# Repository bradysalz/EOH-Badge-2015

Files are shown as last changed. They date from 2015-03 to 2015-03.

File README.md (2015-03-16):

# EOH Badge 2015
This repo has the badges I designed for University of Illinois' [Engineering Open House] (http://eoh.ec.illinois.edu). The [student branch of IEEE] (http://ieee.illinois.edu) funded the creation of about 350 of these little guys, and they were a huge hit with the crowd!

badge

## How It Works
We flashed simple Arduino code onto a ATtiny85's in order to sample the voltage level between a photocell and a resistor. The sampling had a period of around 50ms, or 20Hz. If it detected a change from light to dark in that time period, it would turn on and slowly fade out the LEDs. 

## To Do
- [ ] Swap from polling to interrupt code ( ISR ADC_vect)
- [x] Add pin clasps to BOM somehow?
- [x] Edit PCB to properly handle SPDT switch (currently in parallel AKA useless)
- [x] Edit PCB to wire RESET to VDD (had to write it as GPIO, can't reflash, not the biggest problem)

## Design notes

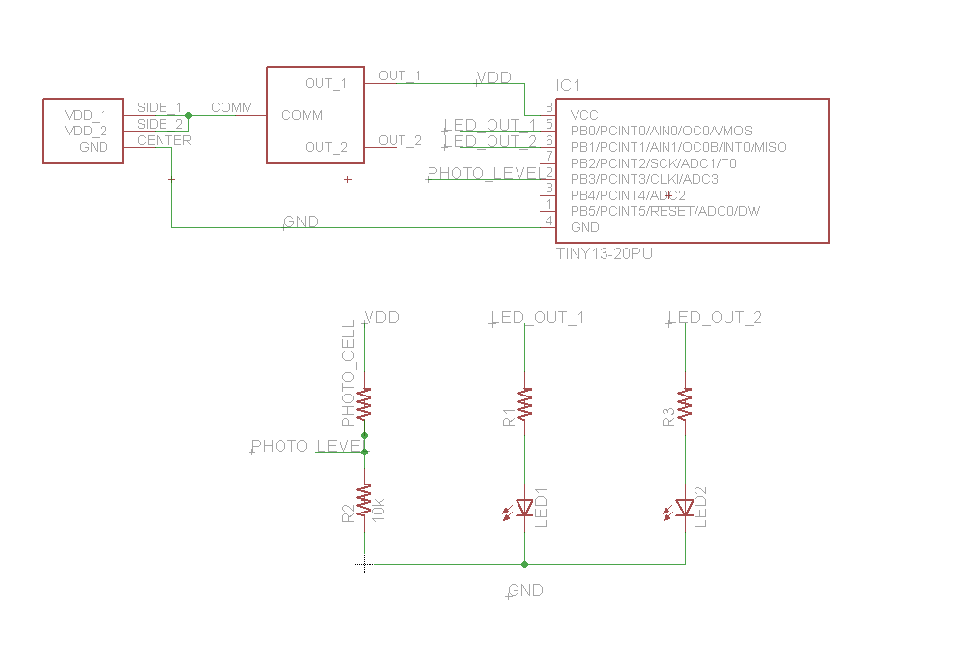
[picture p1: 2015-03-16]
eagle/schematic.PNG

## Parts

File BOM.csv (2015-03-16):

SUPPLIER | PART NAME | PART NUMBER | COST PER UNIT | QUANTITY | NET COST
Digikey | ATtiny85 | ATTINY85-20PU-ND | 1.08 | 350 | 378
Digikey | Photocell | PDV-P8103-ND | 0.42 | 350 | 147
Digikey | 51kOhm Resistor | CF14JT51K0CT-ND | 0.01624 | 350 | 5.684
Digikey | Orange Led | 754-1896-ND | 0.07752 | 350 | 27.132
Digikey | Blue LED | 732-5011-ND | 0.3226 | 350 | 112.91
Digikey | 9.1Ohm Resistor | P9.1BACT-ND | 0.02016 | 350 | 7.056
Digikey | 40.2Ohm Resistor | PPC40.2YCT-ND | 0.06112 | 350 | 21.392
Sparkfun | Coin Cell Battery | PRT-00338 | 1.56 | 350 | 546
Sparkfun | Coin Cell Holder | PRT-11892 | 0.76 | 350 | 266
Sparkfun | SPDT Switch | COM-09609 | 0.6 | 350 | 210
Amazon | Pin Clasp (Tie Tack) | Example | 0.42 | 350 | 145.83
 |  |  |  |  |  | Sum | 1867.007333

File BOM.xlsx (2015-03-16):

SUPPLIER | PART NAME | PART NUMBER | COST PER UNIT | QUANTITY | NET COST
Digikey | ATtiny85 | ATTINY85-20PU-ND (http://www.digikey.com/scripts/DkSearch/dksus.dll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) | 1.08 | 350 | 378
Digikey | Photocell | PDV-P8103-ND (http://www.digikey.com/scripts/DkSearch/dksus.dll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) | 0.42 | 350 | 147
Digikey | 51kOhm Resistor | CF14JT51K0CT-ND (http://www.digikey.com/scripts/DkSearch/dksus.dll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) | 0.01624 | 350 | 5.684
Digikey | Orange Led | 754-1896-ND (http://www.digikey.com/scripts/DkSearch/dksus.dll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) | 0.07752 | 350 | 27.132
Digikey | Blue LED | 732-5011-ND (http://www.digikey.com/scripts/DkSearch/dksus.dll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) | 0.3226 | 350 | 112.91
Digikey | 9.1Ohm Resistor | P9.1BACT-ND (http://www.digikey.com/scripts/DkSearch/dksus.dll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) | 0.02016 | 350 | 7.056
Digikey | 40.2Ohm Resistor | PPC40.2YCT-ND (http://www.digikey.com/scripts/DkSearch/dksus.dll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) | 0.06112 | 350 | 21.392
Sparkfun | Coin Cell Battery | PRT-00338 (https://www.sparkfun.com/products/338) | 1.56 | 350 | 546
Sparkfun | Coin Cell Holder | PRT-11892 (https://www.sparkfun.com/products/11892) | 0.76 | 350 | 266
Sparkfun | SPDT Switch | COM-09609 (https://www.sparkfun.com/products/9609) | 0.6 | 350 | 210
Amazon | Pin Clasp (Tie Tack) | Example (http://www.amazon.com/gp/product/B002QNPWNE/ref=oh_aui_detailpage_o00_s00?ie=UTF8&psc=1) | 0.42 | 350 | 145.83
 |  |  |  |  |  | Sum | 1867.007333

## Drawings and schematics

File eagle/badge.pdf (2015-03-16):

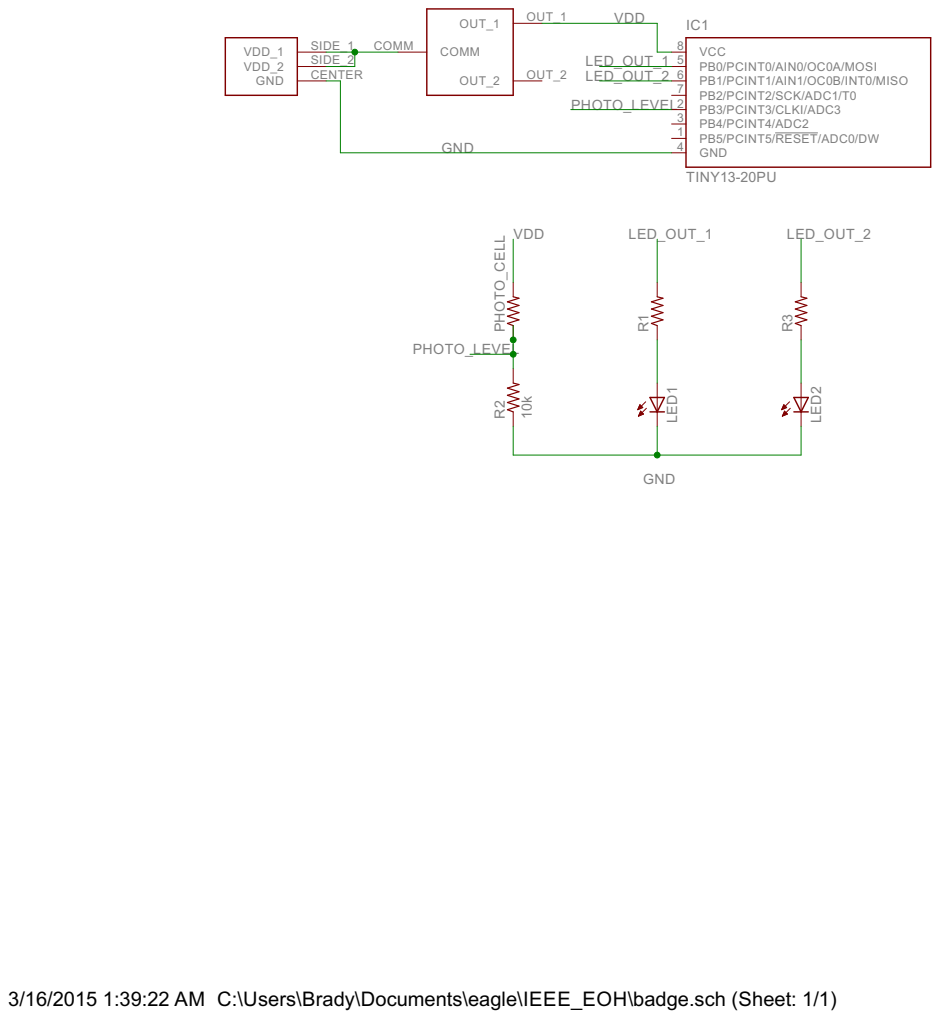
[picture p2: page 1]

3/16/2015 1:39:22 AM C:\Users\Brady\Documents\eagle\IEEE_EOH\badge.sch (Sheet: 1/1)

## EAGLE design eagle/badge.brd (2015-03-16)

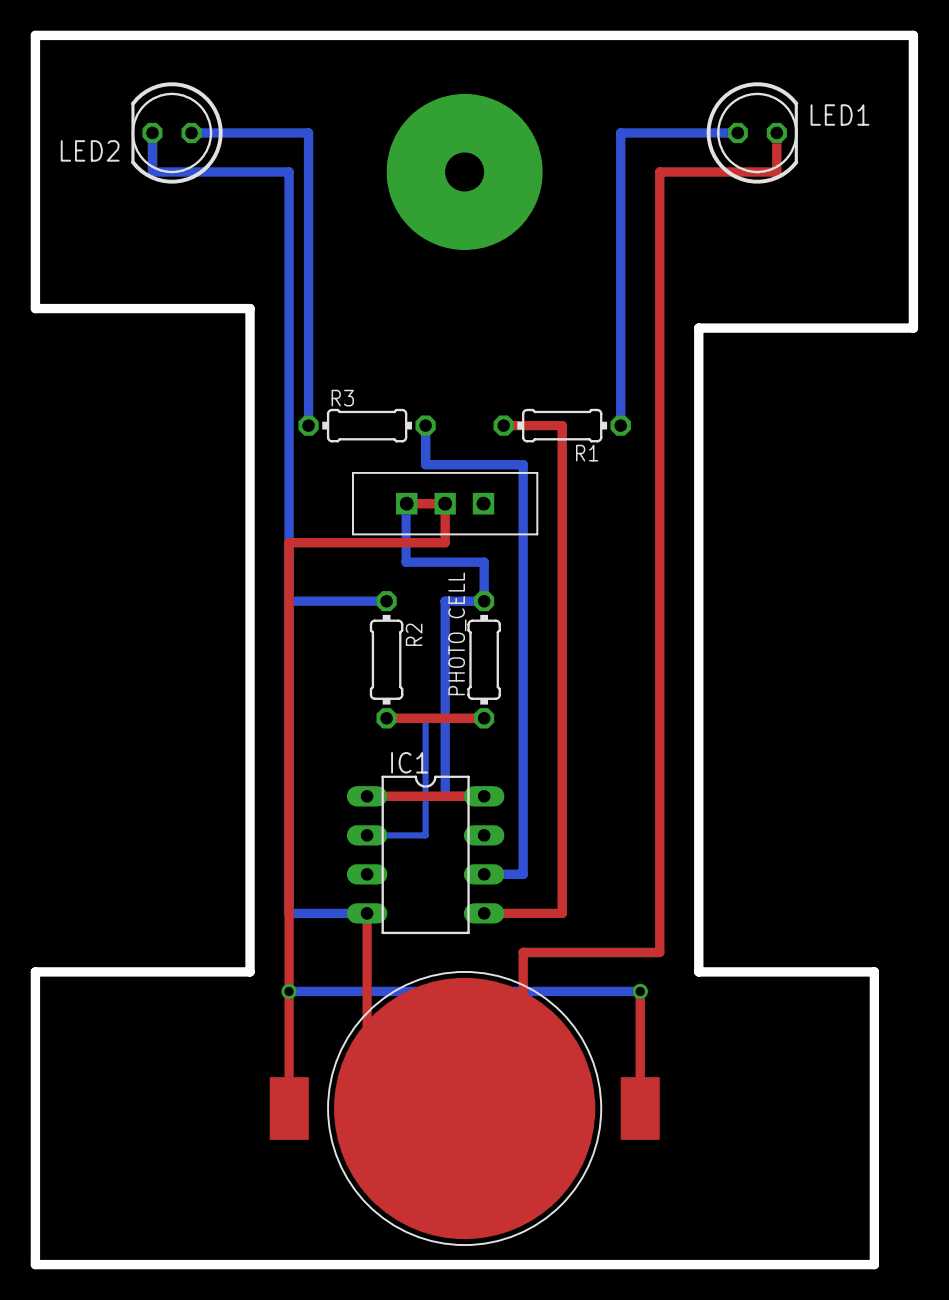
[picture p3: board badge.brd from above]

Board: 2 copper layers, 57.1 x 80.0 mm, 9 parts (0 on the bottom side), 7 nets.

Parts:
IC1: TINY13-20PU; DIL08
LED1, LED2: LED5MM
PHOTO_CELL: 0204/7
R1, R3: 0204/7
R2: 10k; 0204/7
U$1: COIN_CELL_SPARKFUN
U$2: SPST_SPARKFUN; SPDT_SPARKFUN

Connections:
GND: IC1.4, LED1.K, LED2.K, R2.1, U$1.CENTER
LED_OUT_1: IC1.5, R1.2
LED_OUT_2: IC1.6, R3.2
unnamed: LED1.A, R1.1
unnamed: LED2.A, R3.1
PHOTO_LEVEL: IC1.2, PHOTO_CELL.1, R2.2
VDD: IC1.1, IC1.8, PHOTO_CELL.2, U$1.SIDE_1, U$1.SIDE_2, U$2.COMM, U$2.OUT_1

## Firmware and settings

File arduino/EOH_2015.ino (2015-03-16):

#define ADC_IN 3
#define LED1 0
#define LED2 1
#define RIP_RESET 5
int oldsample = 1024, sample = 1024;

void setup() {
    pinMode(ADC_IN, INPUT);
    pinMode(LED1, OUTPUT);
    pinMode(LED2, OUTPUT);
	
	// these lines aren't needed now that we route VDD correctly
	// keeping them in removes the ability to re-flash the board
    // pinMode(RIP_RESET, OUTPUT);
    // digitalWrite(RIP_RESET, LOW);
}

void fadeout() {
  int i;
  for(i = 255; i >= 0; i--){
    analogWrite(LED1, i);
    analogWrite(LED2, i);
    delay(10);
  }  
}

void loop() {
  sample = analogRead(ADC_IN);
  if (sample < oldsample-15) fadeout();
  
  oldsample = sample;   

  delay(50);
}

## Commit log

2015-03-15 adding BOM (Digikey/Sparkfun only)
    [BOM.xlsx]
2015-03-15 added EagleCAD schem/board
    [badge.brd, badge.sch]
2015-03-16 updated schematic/board with correct VDD wiring
    Might not be in sync now (between schematic and board), but the data is
    correct. The problem was the battery output and switch output
    accidentally had the same label, so the switch was being bypassed.
    Correct this routing, as well as routing VDD to \bar{RESET} so we
    wouldn't have to lose that functionality by changing RESET to a GPIO
    [badge.brd, badge.sch]
2015-03-16 removed software RESET pin change
    Since the board is now fixed, we can continue to use RESET in the way
    it's meant to be used. This means the chip is reusable and we don't lose
    the ability to re-flash it.
    [EOH_2015.ino]
2015-03-16 added pin clasp to BOM, added CSV format
    Basically just making it pretty
    [BOM.csv, BOM.xlsx]
